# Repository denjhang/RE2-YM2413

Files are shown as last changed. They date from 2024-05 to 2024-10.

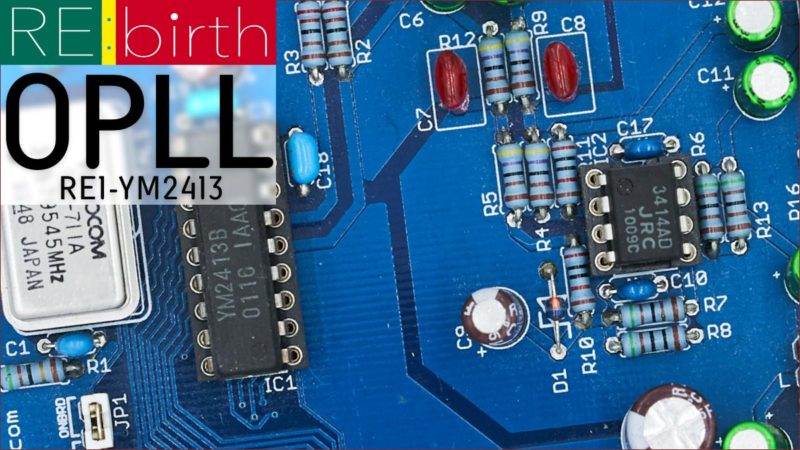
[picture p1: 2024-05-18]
原版图片/eye_RE1-YM2413-800x450.jpg

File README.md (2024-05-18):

# RE2-YM2413
 Functionally verified RE: Birth 2nd sound card. This project refers to the YM2413 audio circuit of the PS98 project. The highlight is the use of differential amplification (instead of the inverting addition used by FMPAC) to mix the MO and RO together and cancel all busses. noise and power supply noise, making this design excellent. In addition, the design supports all YM2413 clone chips, such as YM2413 THINK, U2413, MY2413, U3567, and UM3567. The compatible switching circuit refers to MegaGRRL.

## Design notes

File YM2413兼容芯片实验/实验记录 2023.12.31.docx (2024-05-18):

# 需要下拉20k组：

## 1. UM3567 9251-AW

鼓声偏大，某些自带音色破音，如管风琴，颤音琴

clubster破音

## 2. 3567 HX881(1) 9438

鼓声偏小，无明显破音

clubster正常

总线噪音偏大

## 3. YM2413B 0536 SABQ

一切正常

## 4. YM2420

F-num寄存器不同导致音高错乱

## 5. YM2413 9729 HAAG

完美的原版

## 6. YM2413B 0411 IABO

完美的原版

7. UM3567 9203-AS 528570

鼓声偏大，某些自带音色破音，如管风琴，颤音琴

clubster破音

## 8. UM3567 9204-AW 520590

鼓声正常，某些自带音色破音，如管风琴，颤音琴

clubster破音

## 9. YMF281

完美的原版，音色不同

## 10. UM3567 9001S

同时使用不同的音色超过2个时，旋律音色自动变为正弦波。

最搞笑的版本。

有的芯片却是正常的，和91xx，92xx的一样破音。

## 11. 3567 HX881(1) 9610

RO声音特别小，搞笑了这个版本，必须退货

## 12. U3567 HX881(1) 9809

良好的克隆，耦合噪音偏小

## 13. UM3567 9317-AM 606532

鼓声正常，某些自带音色破音，如管风琴，颤音琴

clubster破音

## 14. UM3567 0440 （无UMC Logo）

良好的克隆

## 15. U2413 0408

需要下拉电阻的版本，还不错

# 无需下拉20K组

## 1. UM3567 0419/0623

声音很大，无明显破音

clubster正常

慢速曲目可以无时钟运行（笑），短暂正常

耦合噪音略大

## 2. 2413（无批号）

耦合噪音偏大，

## 3. U2413（无批号）

耦合噪音偏大

## 4. Monkey MY2413 T1108B

音量大，耦合噪音偏大

## 5. UM2413 0623/0633/0828

音量大，耦合噪音偏大

## 6. YM2413 9848 HACG

打磨丝印的U2413系列克隆芯片。

音量大，耦合噪音偏大

## 7. YM2413 9848 HACG

打磨丝印的U2413系列克隆芯片。

音量比U2413小，耦合噪音很大

## 8. U3567 HX881(1) 9904/9906

音量大，耦合噪音偏大

## 9. U2413 0421

不需要下拉电阻的版本，和其他克隆一样音量大

## 10. 123123123123

## 11. 123123123123

## 12. 123123123123

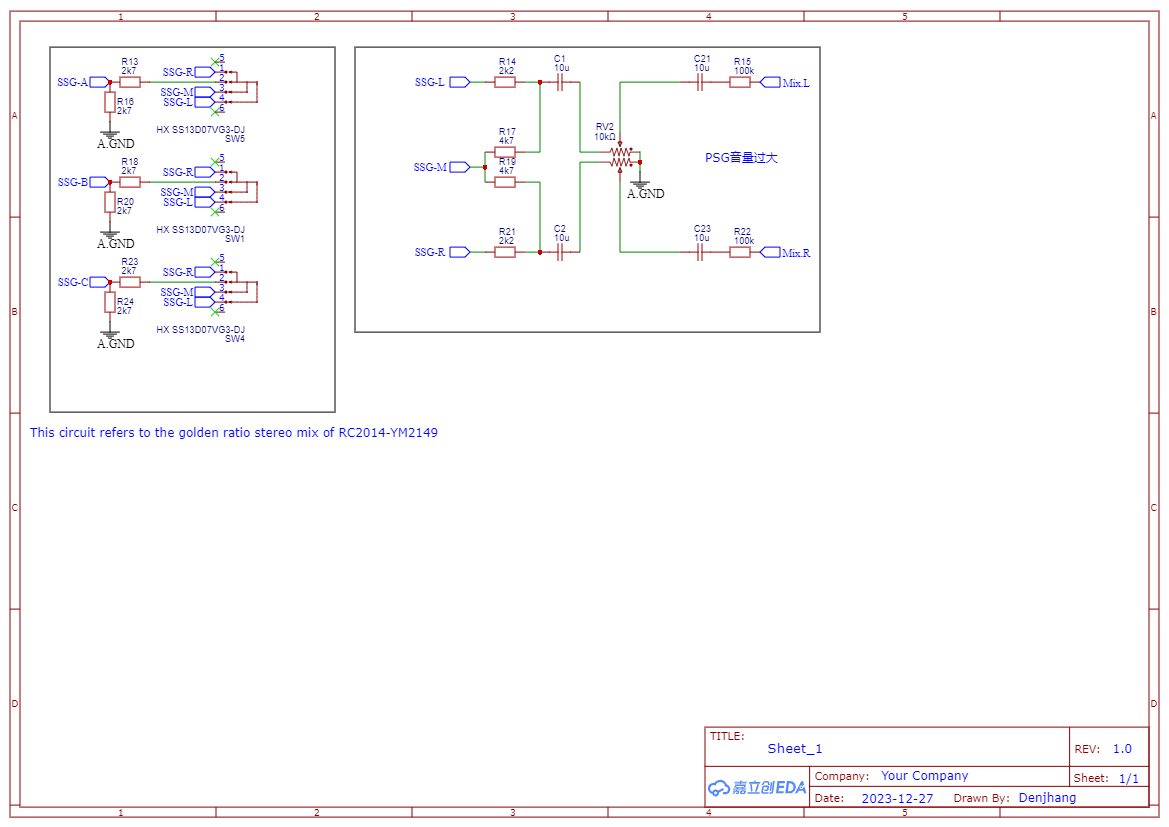
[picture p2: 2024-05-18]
FMPAC-NEW/Schematic_FMPAC-5V-NEW_2023-12-27/PSG.png

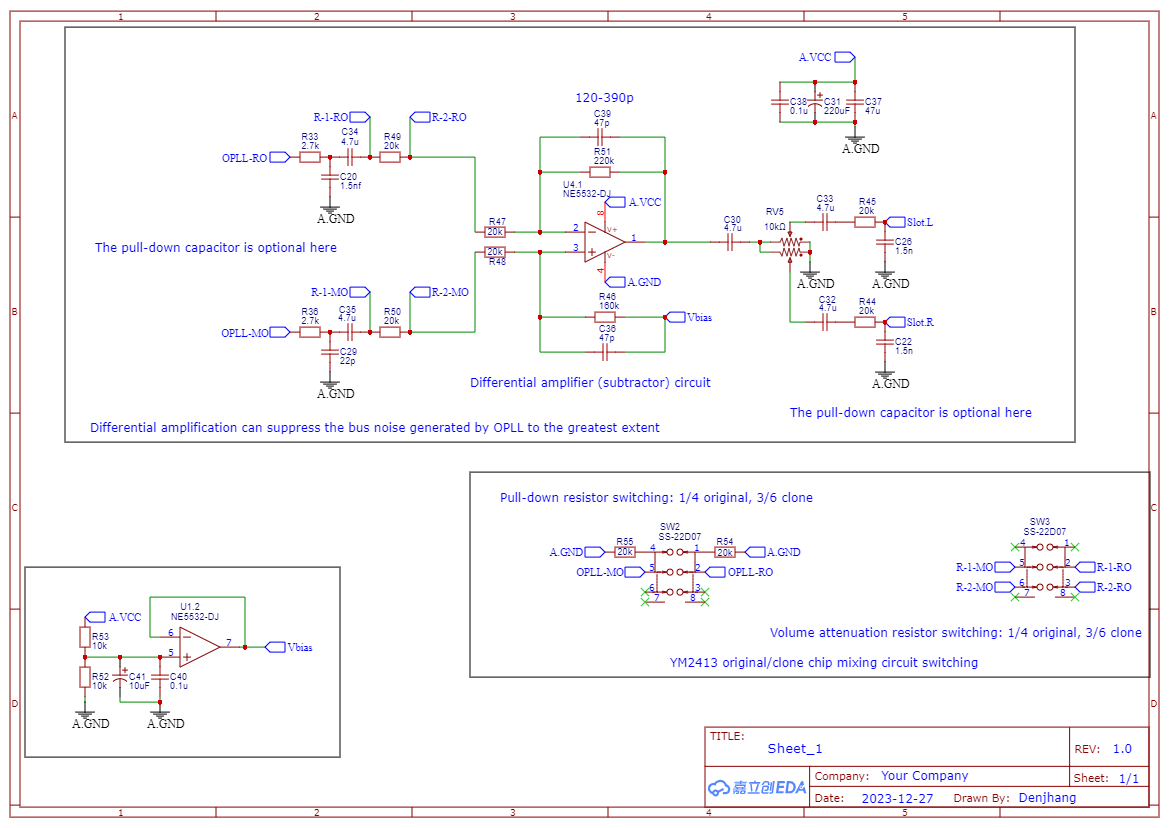
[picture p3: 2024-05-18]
FMPAC-NEW/Schematic_FMPAC-5V-NEW_2023-12-27/OPLL-5V.png

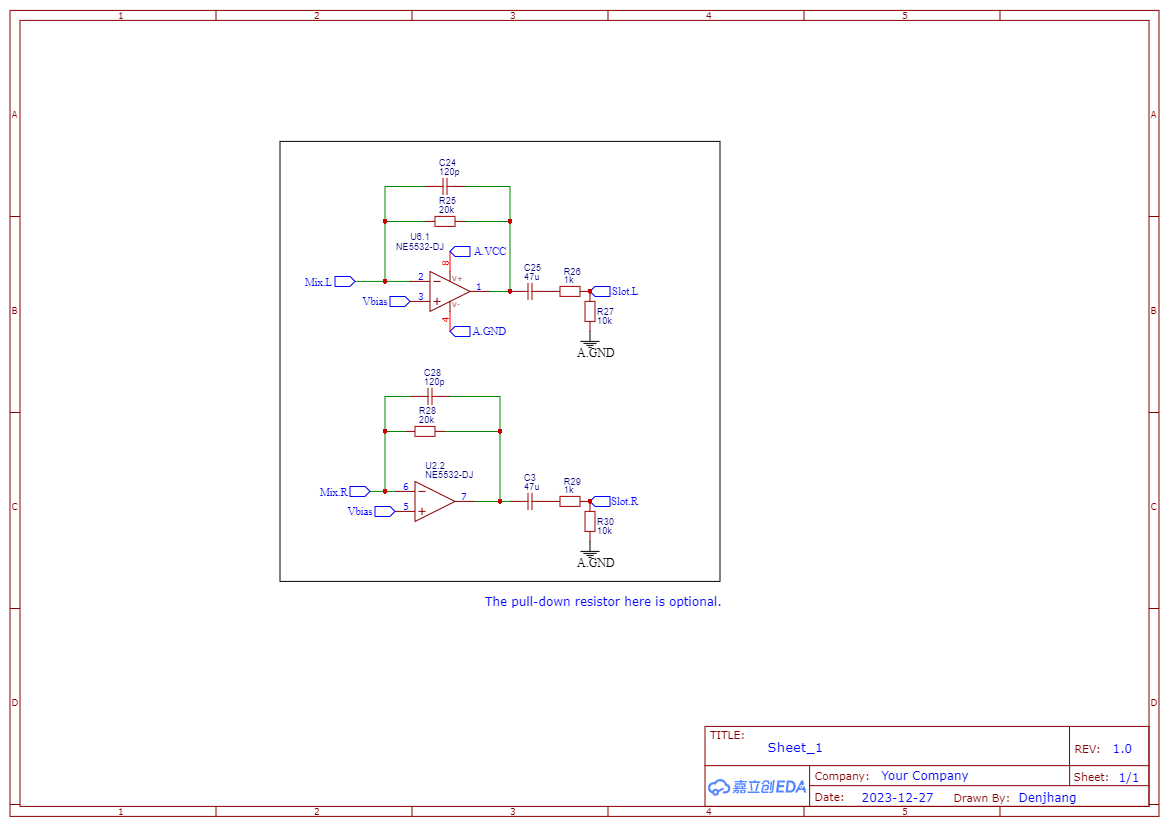
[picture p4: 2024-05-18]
FMPAC-NEW/Schematic_FMPAC-5V-NEW_2023-12-27/Mixer.png

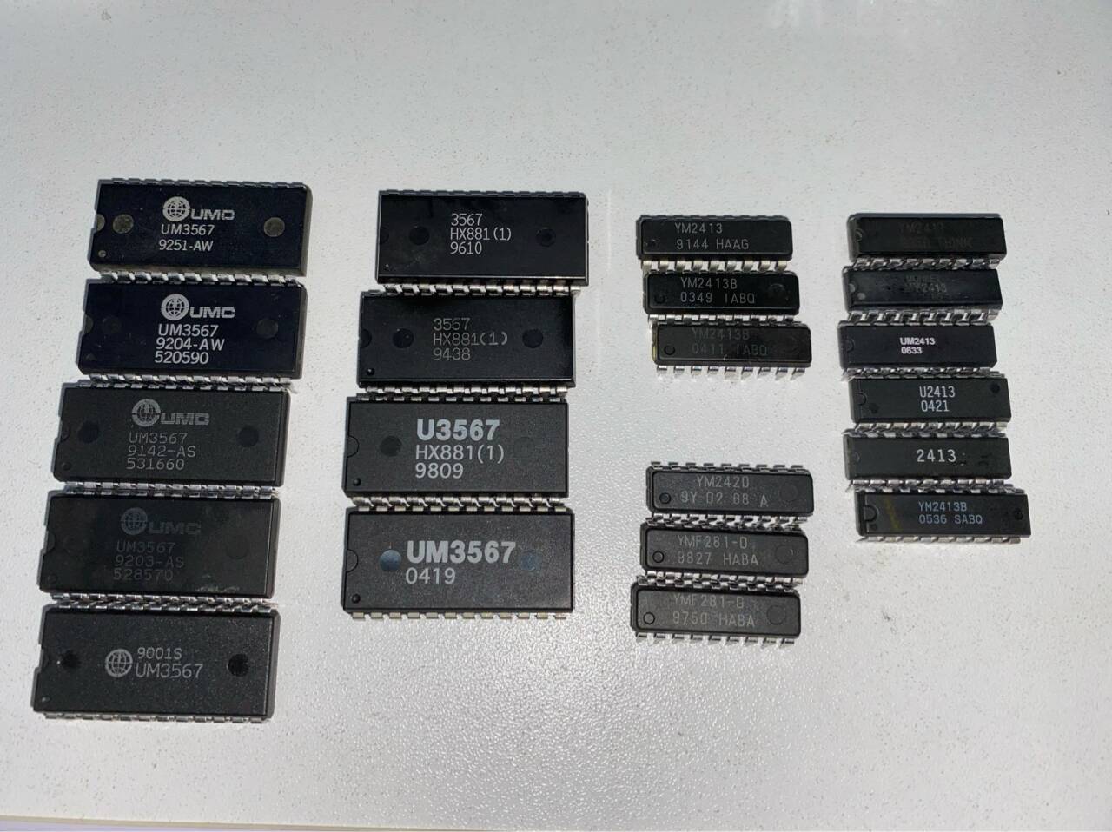
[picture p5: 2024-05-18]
YM2413兼容芯片实验/所有YM2413引脚兼容芯片.jpg

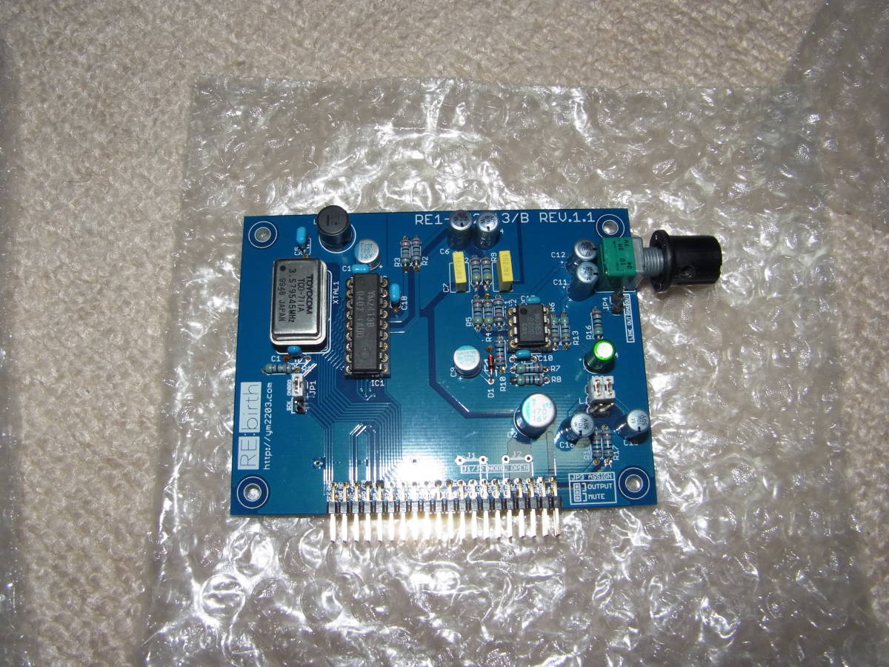
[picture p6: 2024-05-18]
原版图片/原版模块.jpg

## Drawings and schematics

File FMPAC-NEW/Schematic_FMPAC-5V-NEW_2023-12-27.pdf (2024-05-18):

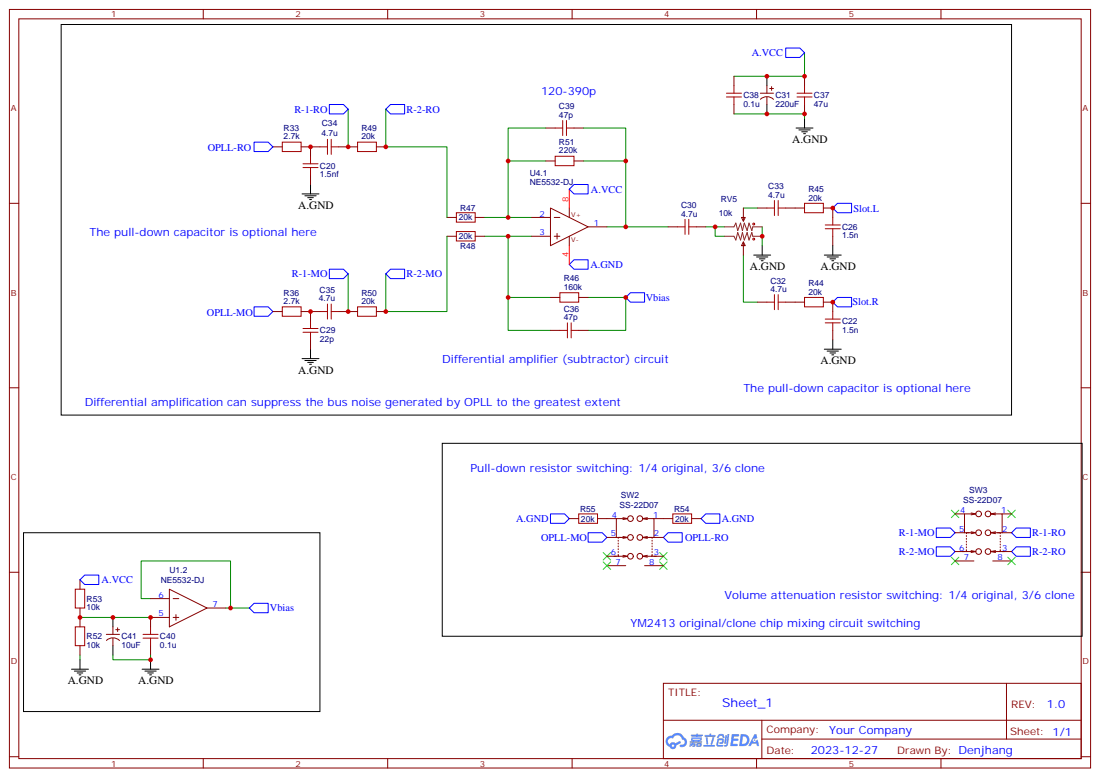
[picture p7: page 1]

The pull-down capacitor is optional here

Differential amplifier (subtractor) circuit

Differential amplification can suppress the bus noise generated by OPLL to the greatest extent

Pull-down resistor switching: 1/4 original, 3/6 clone

Volume attenuation resistor switching: 1/4 original, 3/6 clone

YM2413 original/clone chip mixing circuit switching

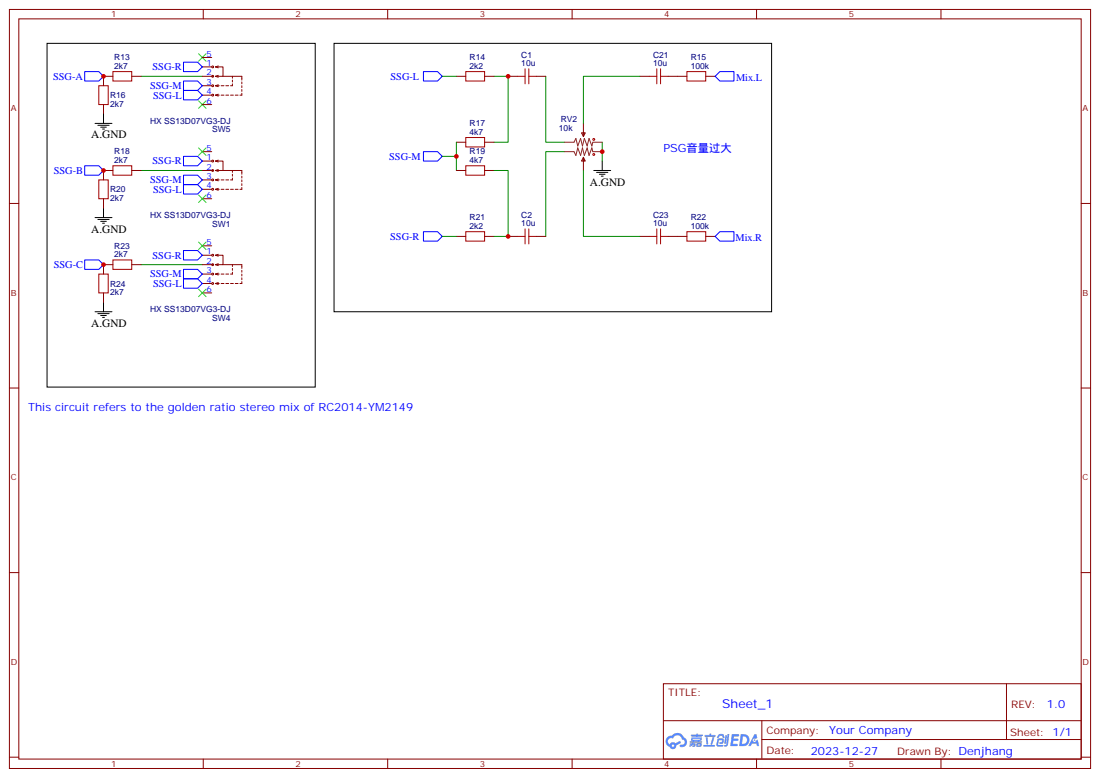
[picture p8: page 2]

This circuit refers to the golden ratio stereo mix of RC2014-YM2149

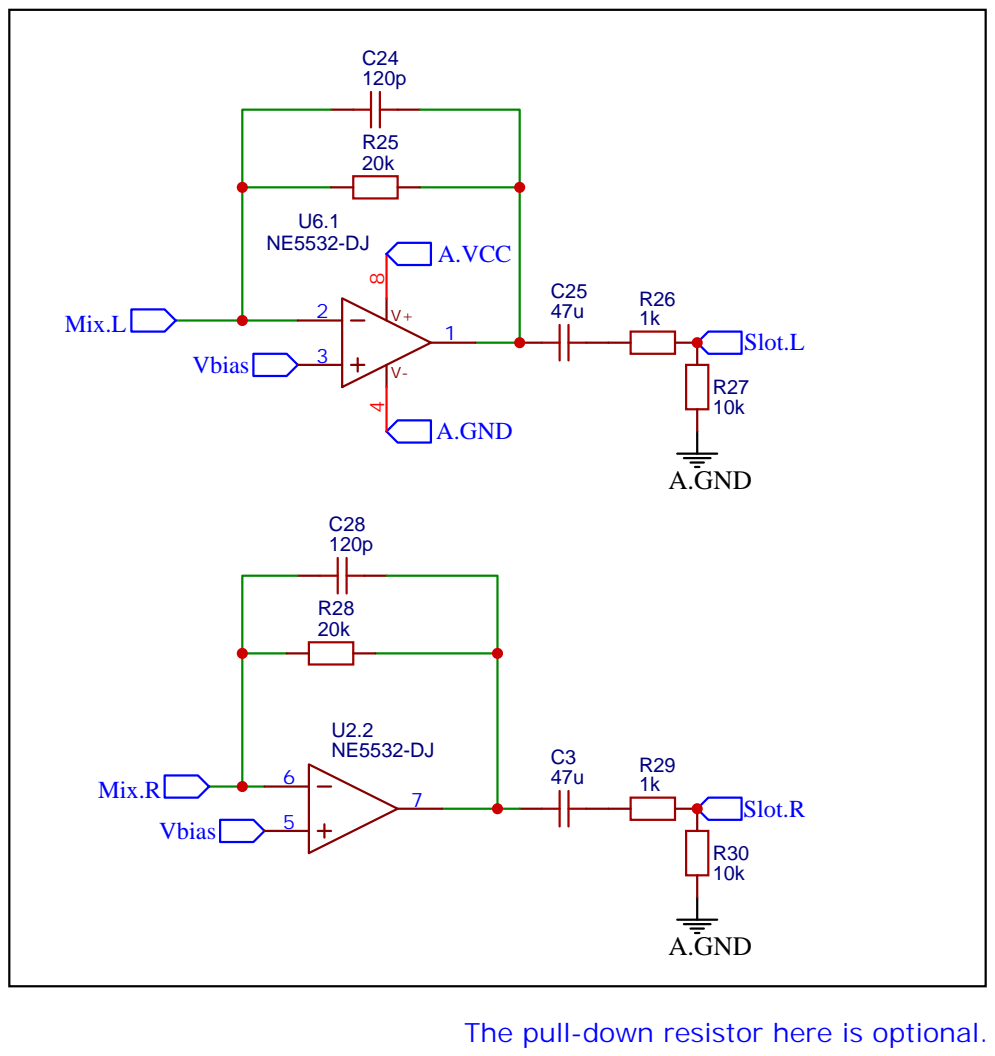
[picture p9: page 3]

The pull-down resistor here is optional.

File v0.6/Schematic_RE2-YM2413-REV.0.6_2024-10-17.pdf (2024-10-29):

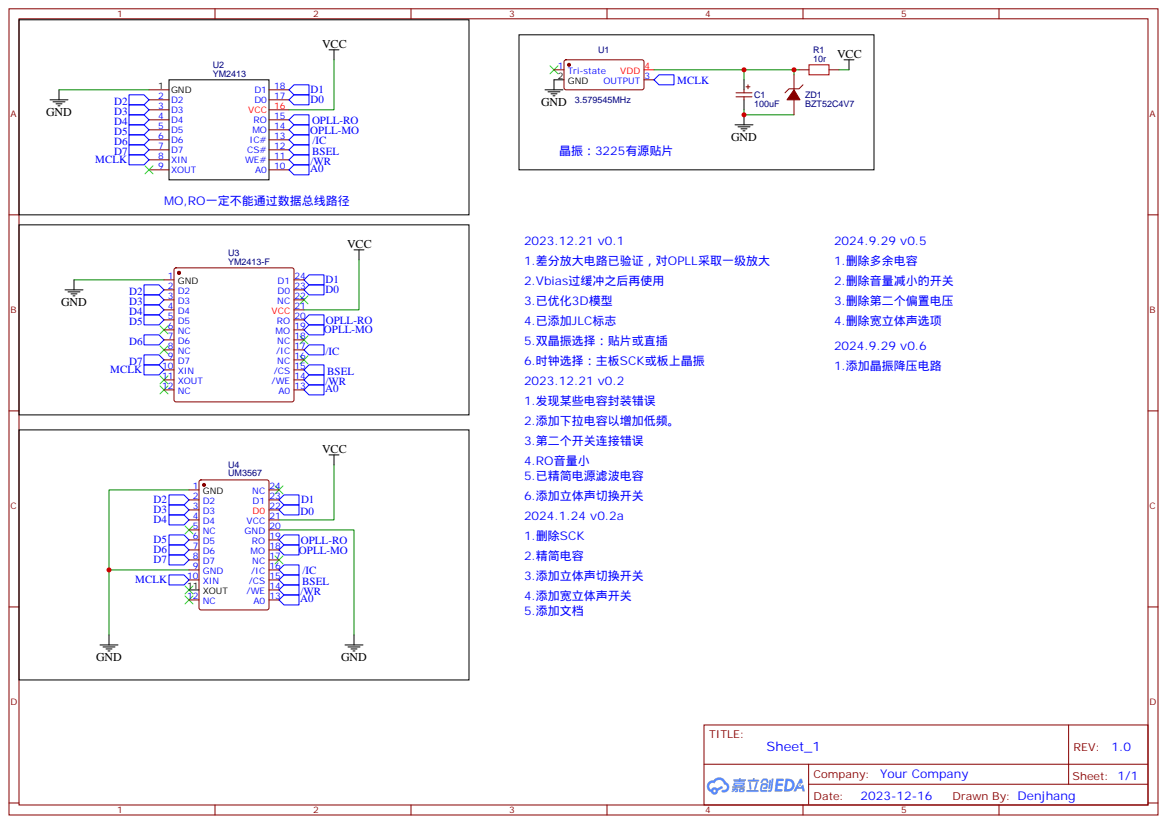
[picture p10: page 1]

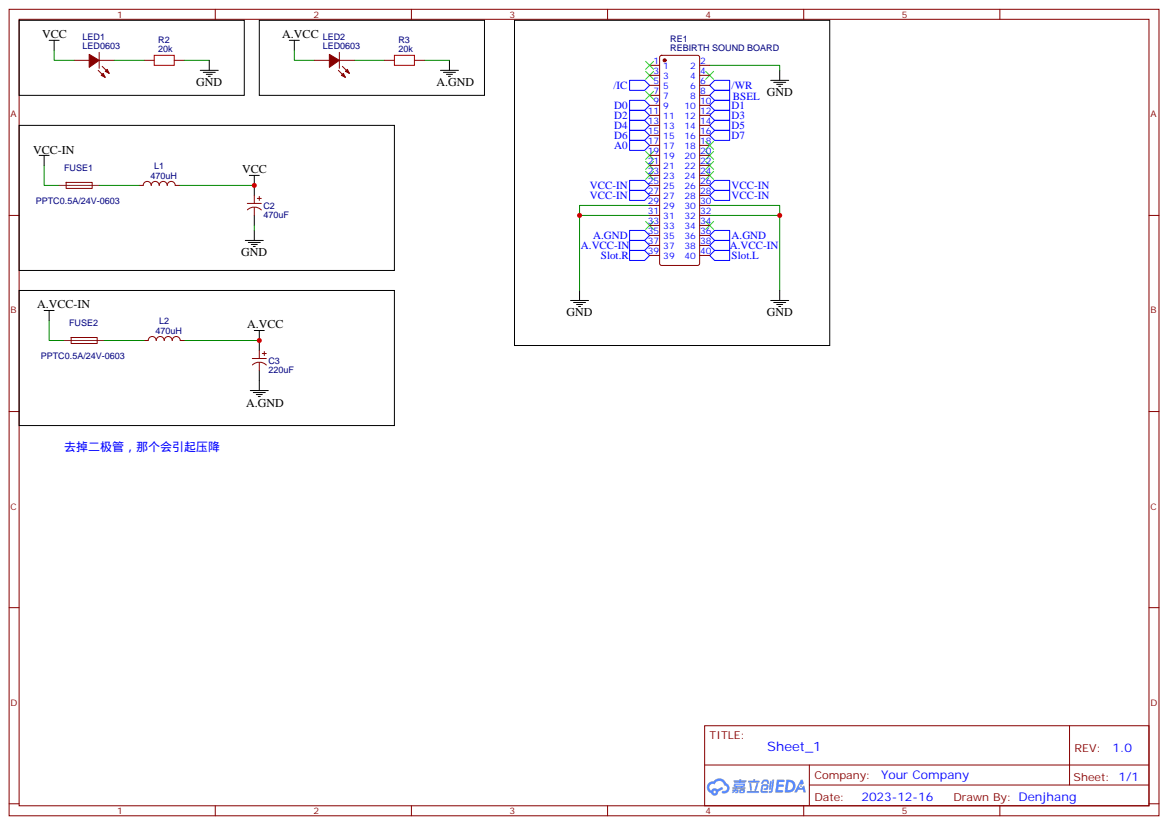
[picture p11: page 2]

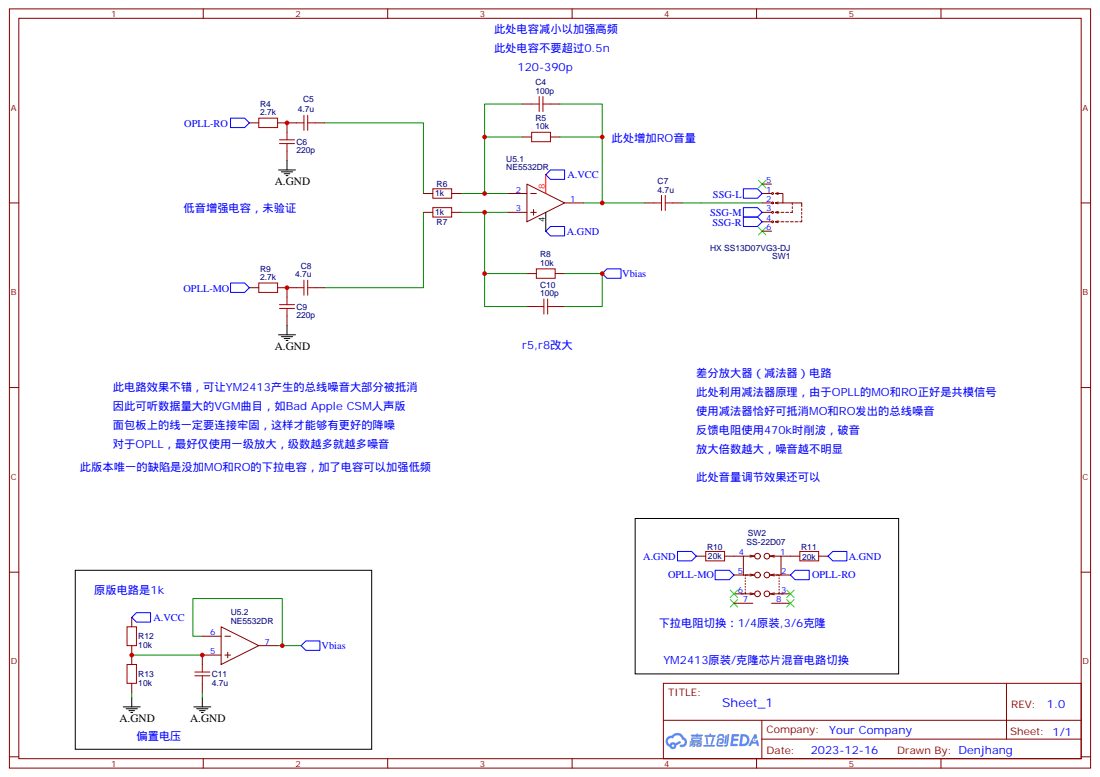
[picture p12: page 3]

因此可听数据量大的VGM曲目，如Bad Apple CSM人声版
面包板上的线一定要连接牢固，这样才能够有更好的降噪
对于OPLL，最好仅使用一级放大，级数越多就越多噪音

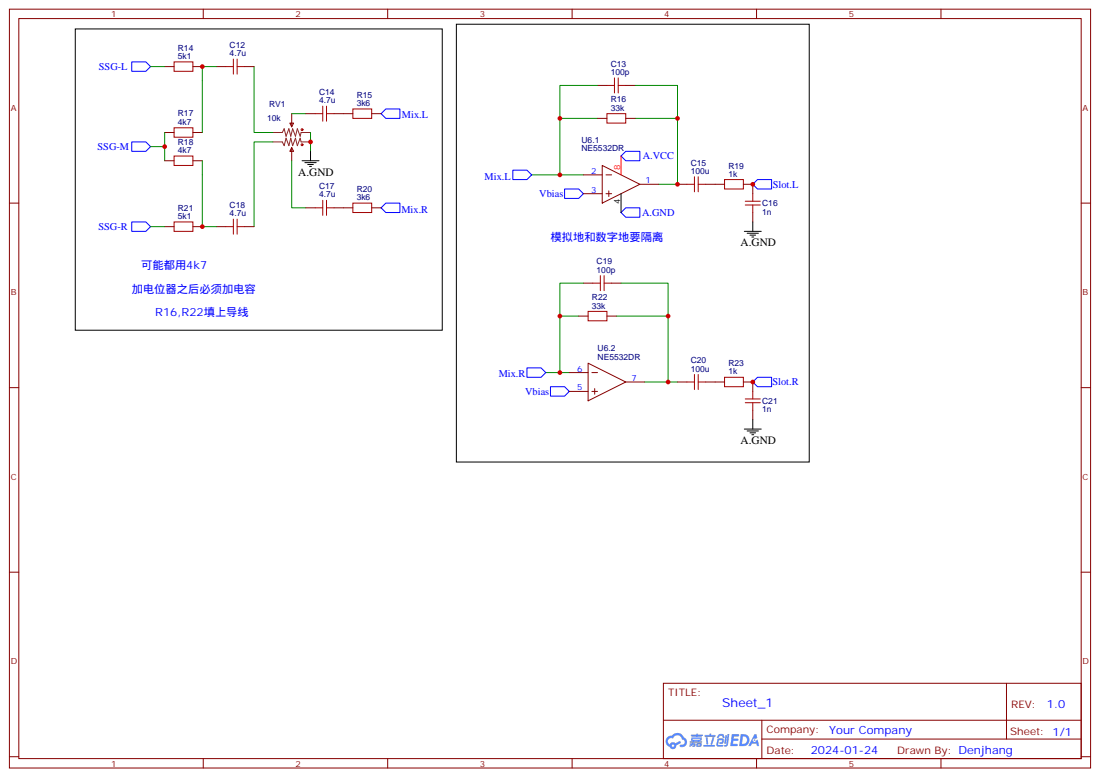
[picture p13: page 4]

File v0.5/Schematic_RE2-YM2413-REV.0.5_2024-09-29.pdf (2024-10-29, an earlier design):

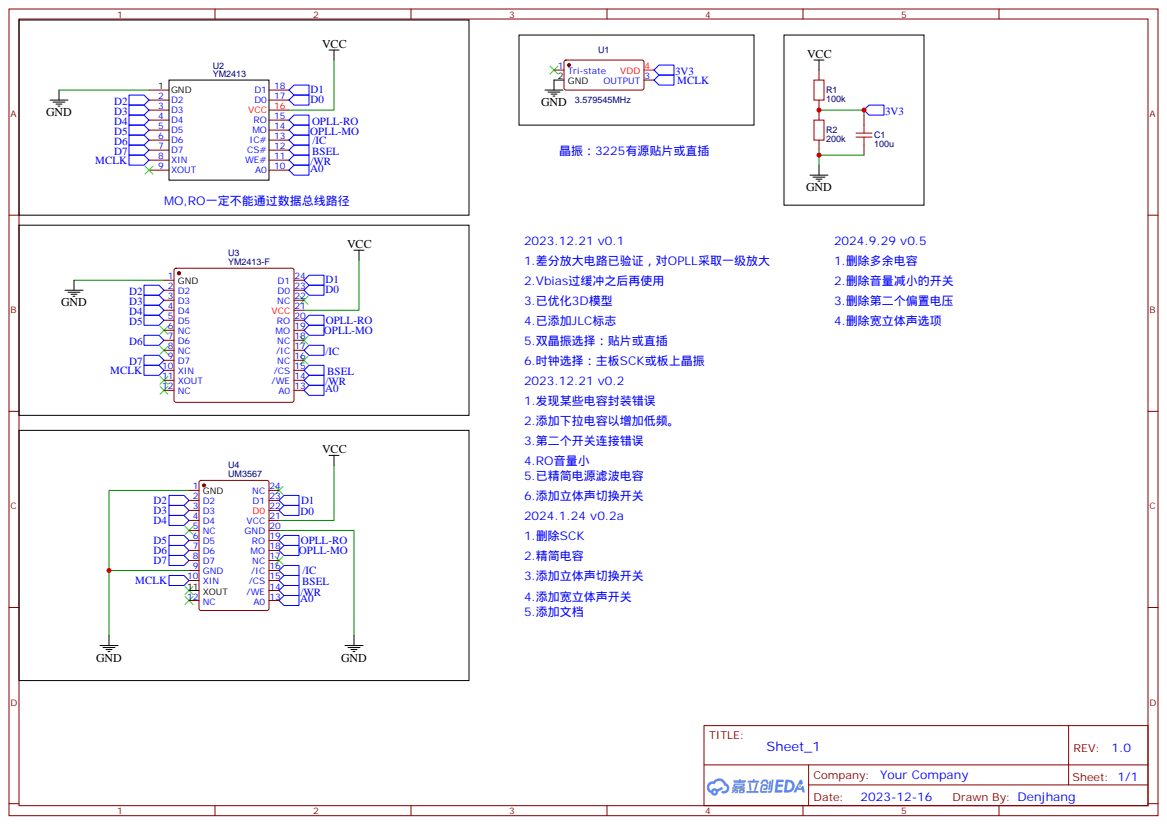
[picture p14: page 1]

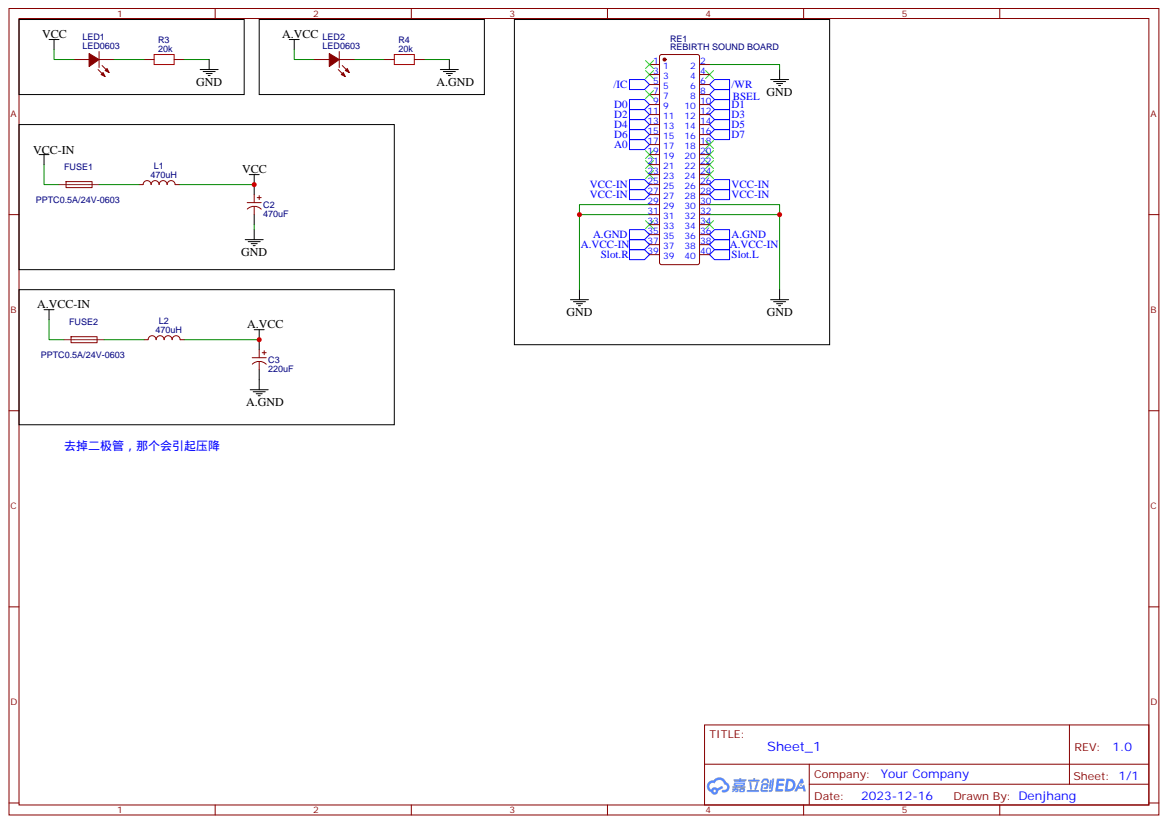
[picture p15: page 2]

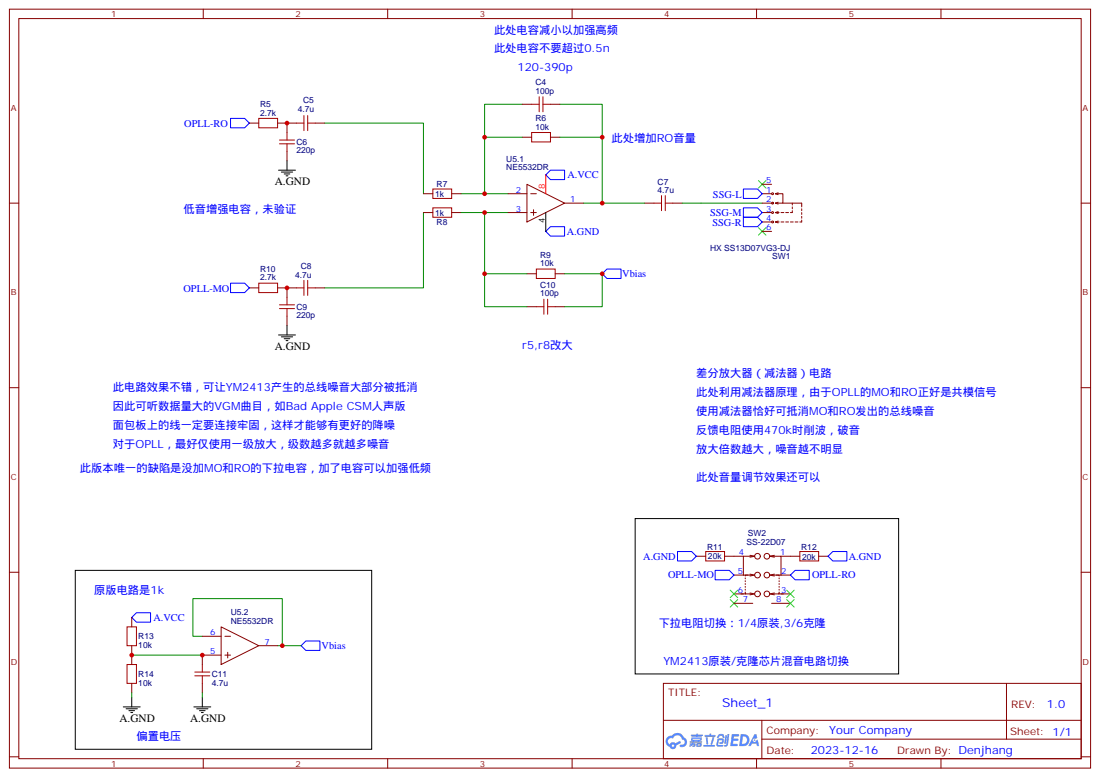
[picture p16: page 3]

因此可听数据量大的VGM曲目，如Bad Apple CSM人声版
面包板上的线一定要连接牢固，这样才能够有更好的降噪
对于OPLL，最好仅使用一级放大，级数越多就越多噪音

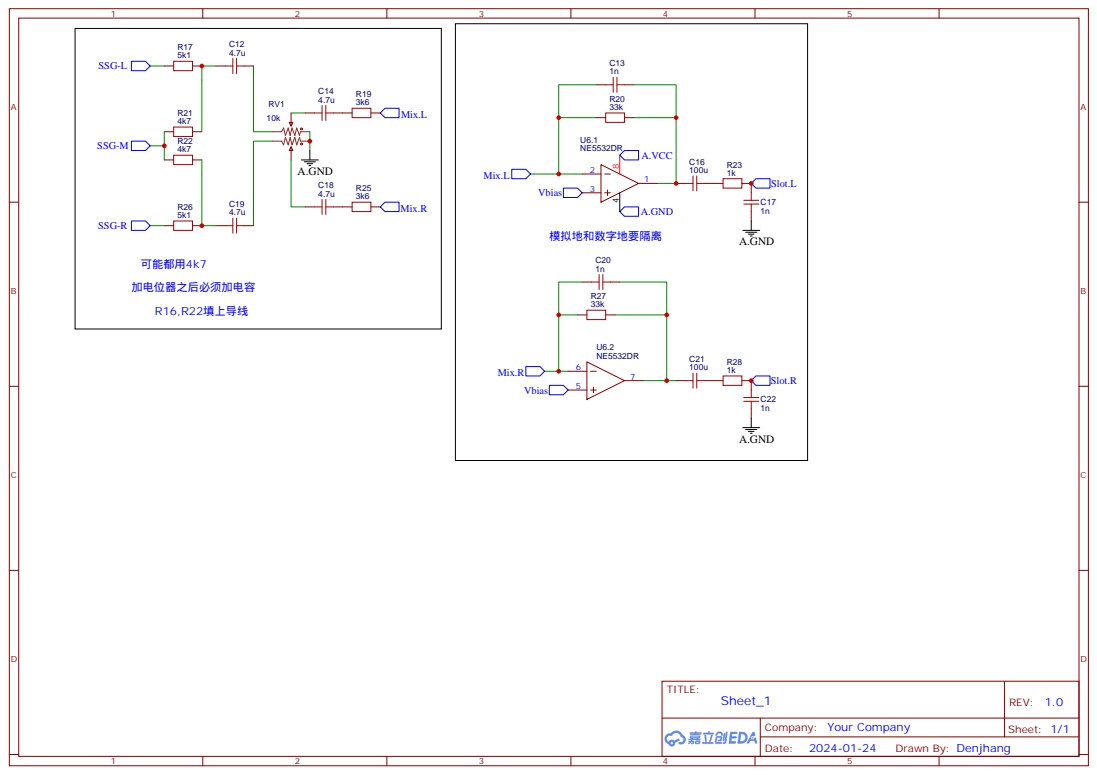
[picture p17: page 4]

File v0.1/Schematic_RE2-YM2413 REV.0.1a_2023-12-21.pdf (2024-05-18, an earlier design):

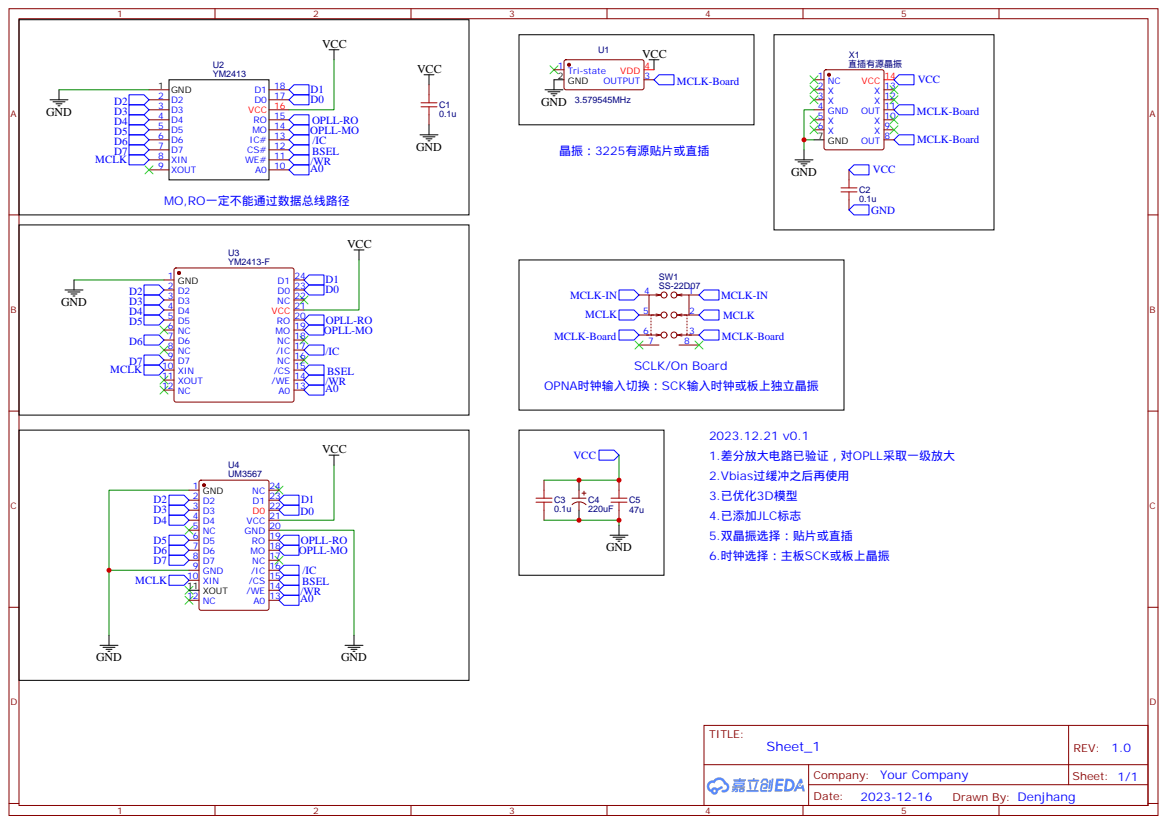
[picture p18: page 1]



此电路效果不错，可让YM2413产生的总线噪音大部分被抵消
因此可听数据量大的VGM曲目，如Bad Apple CSM人声版
面包板上的线一定要连接牢固，这样才能够有更好的降噪
对于OPLL，最好仅使用一级放大，级数越多就越多噪音

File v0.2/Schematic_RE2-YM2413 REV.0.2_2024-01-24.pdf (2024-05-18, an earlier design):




因此可听数据量大的VGM曲目，如Bad Apple CSM人声版
面包板上的线一定要连接牢固，这样才能够有更好的降噪
对于OPLL，最好仅使用一级放大，级数越多就越多噪音


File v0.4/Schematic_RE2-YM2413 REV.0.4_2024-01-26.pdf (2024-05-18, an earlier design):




因此可听数据量大的VGM曲目，如Bad Apple CSM人声版
面包板上的线一定要连接牢固，这样才能够有更好的降噪
对于OPLL，最好仅使用一级放大，级数越多就越多噪音
